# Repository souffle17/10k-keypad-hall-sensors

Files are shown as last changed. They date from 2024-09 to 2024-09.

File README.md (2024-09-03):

# 10k-keypad with variable input hall sensors

A 2x5 mechanical keypad circuit and PCB. The second row is made to support hall-effect switches with variable input, similar to those on rapid trigger/wooting keyboards, in addition to normal switches.          

Footprint "SW_MX_HS_CPG151101S11_1u_no_center" is modified from marbastlib's "SW_MX_HS_CPG151101S11_1u"

### Helpful resources:
- https://guide.zykrah.me/
- https://www.masterzen.fr/2020/05/03/designing-a-keyboard-part-1/
- https://wiki.ai03.com/books/pcb-design/chapter/pcb-designer-guide

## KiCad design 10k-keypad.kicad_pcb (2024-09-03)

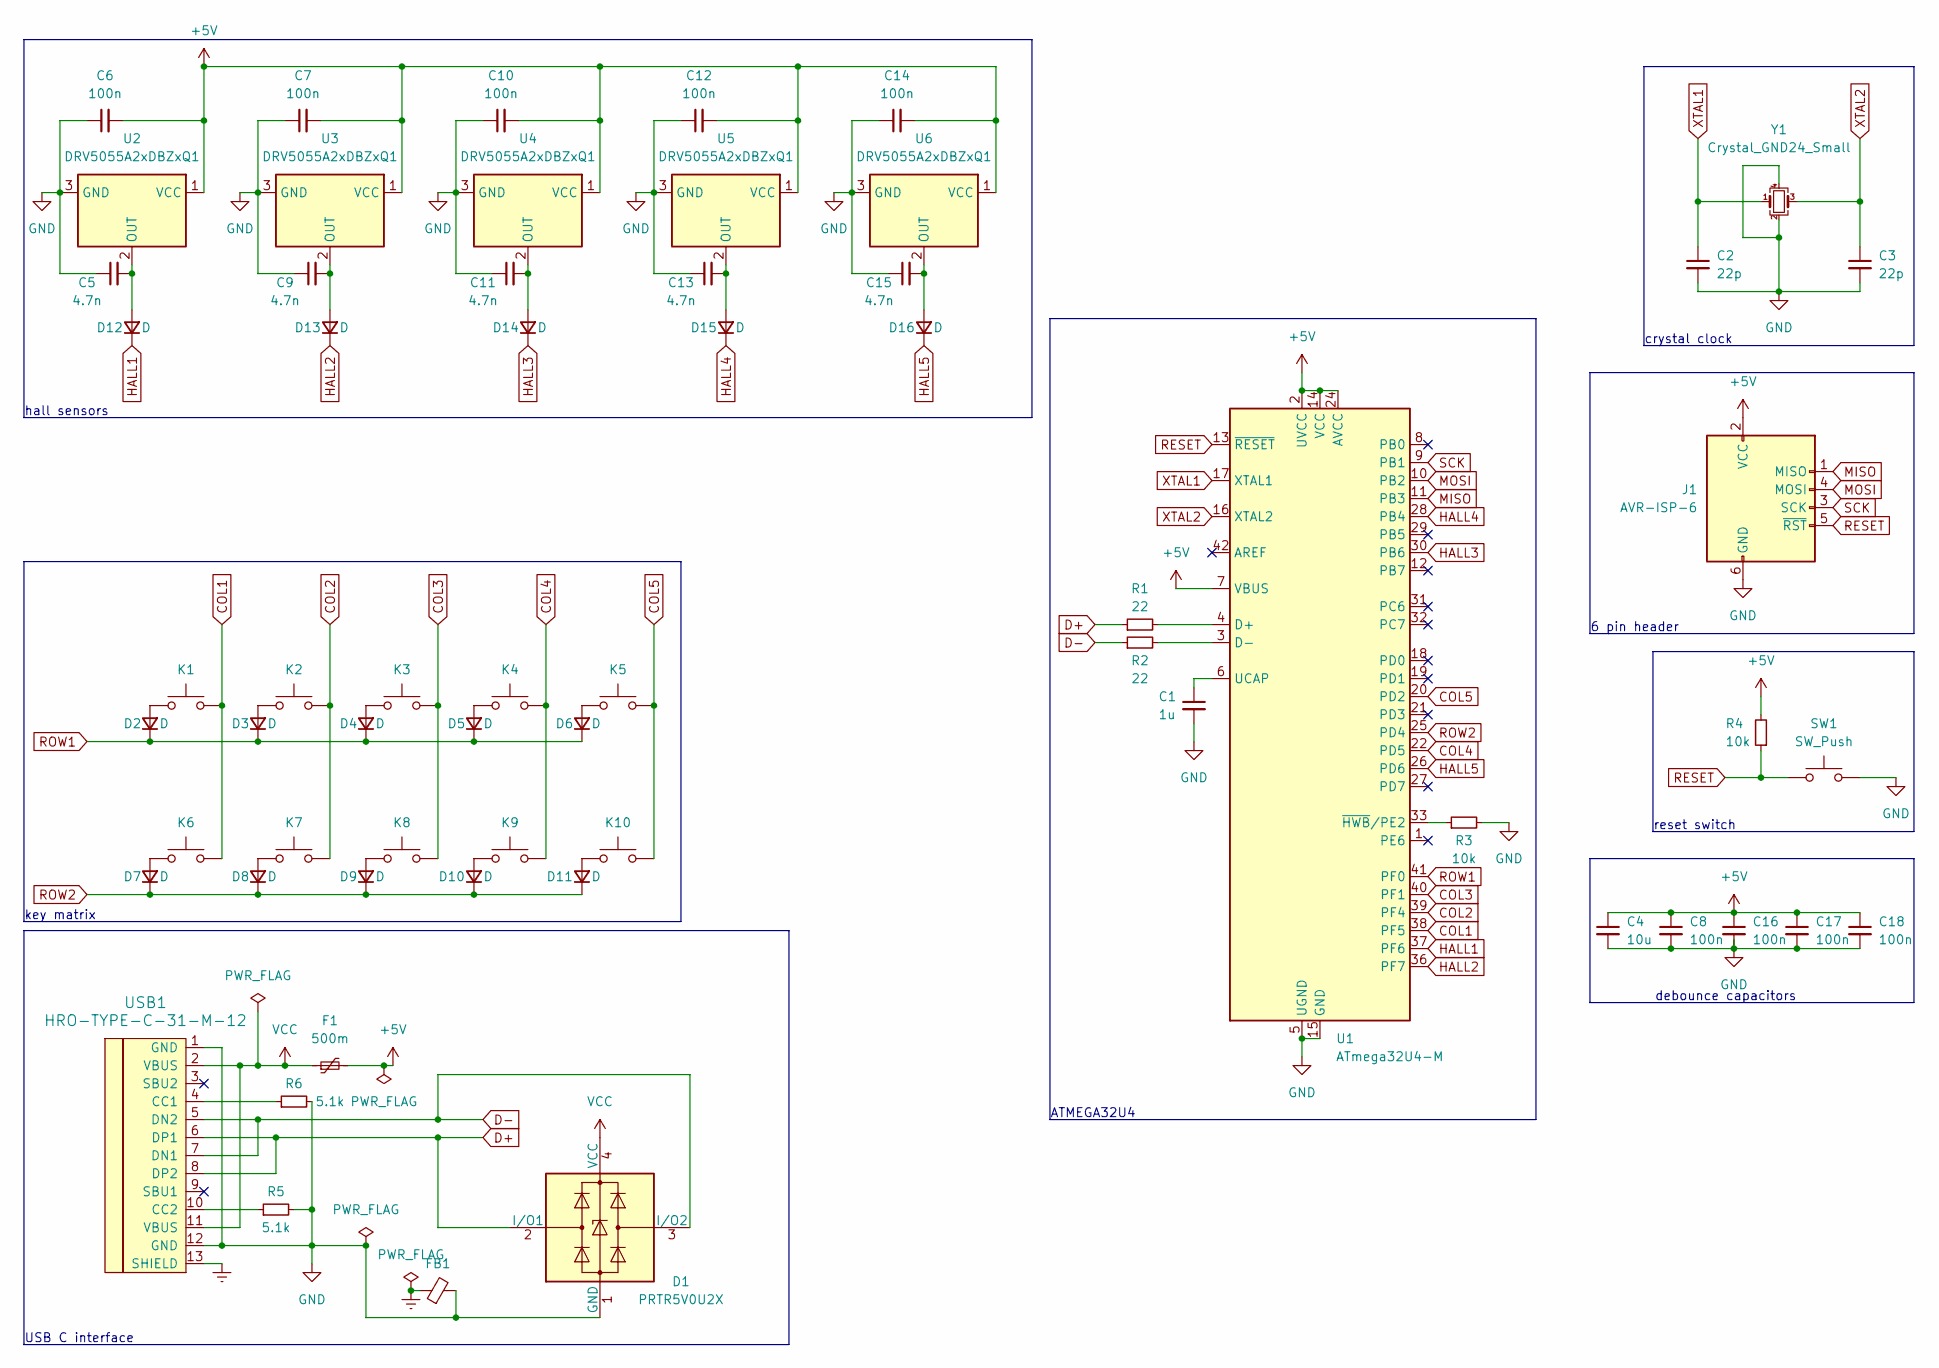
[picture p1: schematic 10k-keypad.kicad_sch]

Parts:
C1: 1u; C_0805_2012Metric_Pad1.18x1.45mm_HandSolder
C2, C3: 22p; C_0805_2012Metric_Pad1.18x1.45mm_HandSolder
C4: 10u; C_0805_2012Metric_Pad1.18x1.45mm_HandSolder
C5, C9, C11, C13, C15: 4.7n; C_0805_2012Metric_Pad1.18x1.45mm_HandSolder
C6, C7, C8, C10, C12, C14, C16, C17, C18: 100n; C_0805_2012Metric_Pad1.18x1.45mm_HandSolder
D1: PRTR5V0U2X; SOT-143
D2, D3, D4, D5, D6, D7, D8, D9, D10, D11, D12, D13, D14, D15, D16: D; D_SOD-123
F1: 500m; Fuse_1206_3216Metric_Pad1.42x1.75mm_HandSolder
FB1: FerriteBead_Small; L_0805_2012Metric_Pad1.15x1.40mm_HandSolder
J1: AVR-ISP-6; Reset_Pretty-Mask
K1, K2, K3, K4, K5: SW_Push; SW_MX_HS_CPG151101S11_1u
K6, K7, K8, K9, K10: SW_Push; SW_MX_HS_CPG151101S11_1u_no_center
R1, R2: 22; R_0805_2012Metric_Pad1.20x1.40mm_HandSolder
R3, R4: 10k; R_0805_2012Metric_Pad1.20x1.40mm_HandSolder
R5, R6: 5.1k; R_0805_2012Metric_Pad1.20x1.40mm_HandSolder
SW1: SW_Push; SW_SPST_SKQG_WithStem
U1: ATmega32U4-M; QFN-44-1EP_7x7mm_P0.5mm_EP5.2x5.2mm
U2, U3, U4, U5, U6: DRV5055A2xDBZxQ1; SOT-23
USB1: HRO-TYPE-C-31-M-12; HRO-TYPE-C-31-M-12-HandSoldering
Y1: Crystal_GND24_Small; Crystal_SMD_3225-4Pin_3.2x2.5mm_HandSoldering

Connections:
+5V: C4.1, C6.2, C7.2, C8.1, C10.2, C12.2, C14.2, C16.1, C17.1, C18.1, F1.2, J1.2 (VCC), R4.2, U1.2 (UVCC), U1.7 (VBUS), U1.14 (VCC), U1.24 (AVCC), U1.34 (VCC), U1.44 (AVCC), U2.1 (VCC), U3.1 (VCC), U4.1 (VCC), U5.1 (VCC), U6.1 (VCC)
COL1: K1.2, K6.2, U1.38 (PF5)
COL2: K2.2, K7.2, U1.39 (PF4)
COL3: K3.2, K8.2, U1.40 (PF1)
COL4: K4.2, K9.2, U1.22 (PD5)
COL5: K5.2, K10.2, U1.20 (PD2)
D+: D1.2 (I/O1), R1.1, USB1.6 (DP1), USB1.8 (DP2)
D-: D1.3 (I/O2), R2.1, USB1.5 (DN2), USB1.7 (DN1)
Earth: FB1.1, USB1.13 (SHIELD)
GND: C1.2, C2.2, C3.2, C4.2, C5.1, C6.1, C7.1, C8.2, C9.1, C10.1, C11.1, C12.1, C13.1, C14.1, C15.1, C16.2, C17.2, C18.2, D1.1 (GND), FB1.2, J1.6 (GND), R3.2, R5.2, R6.2, SW1.2, U1.5 (UGND), U1.15 (GND), U1.23 (GND), U1.35 (GND), U1.43 (GND), U1.45 (GND), U2.3 (GND), U3.3 (GND), U4.3 (GND), U5.3 (GND), U6.3 (GND), USB1.1 (GND), USB1.12 (GND), Y1.2, Y1.4
HALL1: D12.1 (K), U1.37 (PF6)
HALL2: D13.1 (K), U1.36 (PF7)
HALL3: D14.1 (K), U1.30 (PB6)
HALL4: D15.1 (K), U1.28 (PB4)
HALL5: D16.1 (K), U1.26 (PD6)
MISO: J1.1 (MISO), U1.11 (PB3)
MOSI: J1.4 (MOSI), U1.10 (PB2)
unnamed: D2.2 (A), K1.1
unnamed: D3.2 (A), K2.1
unnamed: D4.2 (A), K3.1
unnamed: D5.2 (A), K4.1
unnamed: D6.2 (A), K5.1
unnamed: D7.2 (A), K6.1
unnamed: D8.2 (A), K7.1
unnamed: D9.2 (A), K8.1
unnamed: D10.2 (A), K9.1
unnamed: D11.2 (A), K10.1
unnamed: C5.2, D12.2 (A), U2.2 (OUT)
unnamed: C9.2, D13.2 (A), U3.2 (OUT)
unnamed: C11.2, D14.2 (A), U4.2 (OUT)
unnamed: C13.2, D15.2 (A), U5.2 (OUT)
unnamed: C15.2, D16.2 (A), U6.2 (OUT)
unnamed: R1.2, U1.4 (D+)
unnamed: R2.2, U1.3 (D-)
unnamed: C1.1, U1.6 (UCAP)
unnamed: R3.1, U1.33 (~HWB/PE2)
unnamed: R6.1, USB1.4 (CC1)
unnamed: R5.1, USB1.10 (CC2)
RESET: J1.5 (~RST), R4.1, SW1.1, U1.13 (~RESET)
ROW1: D2.1 (K), D3.1 (K), D4.1 (K), D5.1 (K), D6.1 (K), U1.41 (PF0)
ROW2: D7.1 (K), D8.1 (K), D9.1 (K), D10.1 (K), D11.1 (K), U1.25 (PD4)
SCK: J1.3 (SCK), U1.9 (PB1)
VCC: D1.4 (VCC), F1.1, USB1.2 (VBUS), USB1.11 (VBUS)
XTAL1: C2.1, U1.17 (XTAL1), Y1.1
XTAL2: C3.1, U1.16 (XTAL2), Y1.3

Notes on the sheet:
crystal clock
hall sensors
key matrix
ATMEGA32U4
USB C interface
reset switch
6 pin header
debounce capacitors

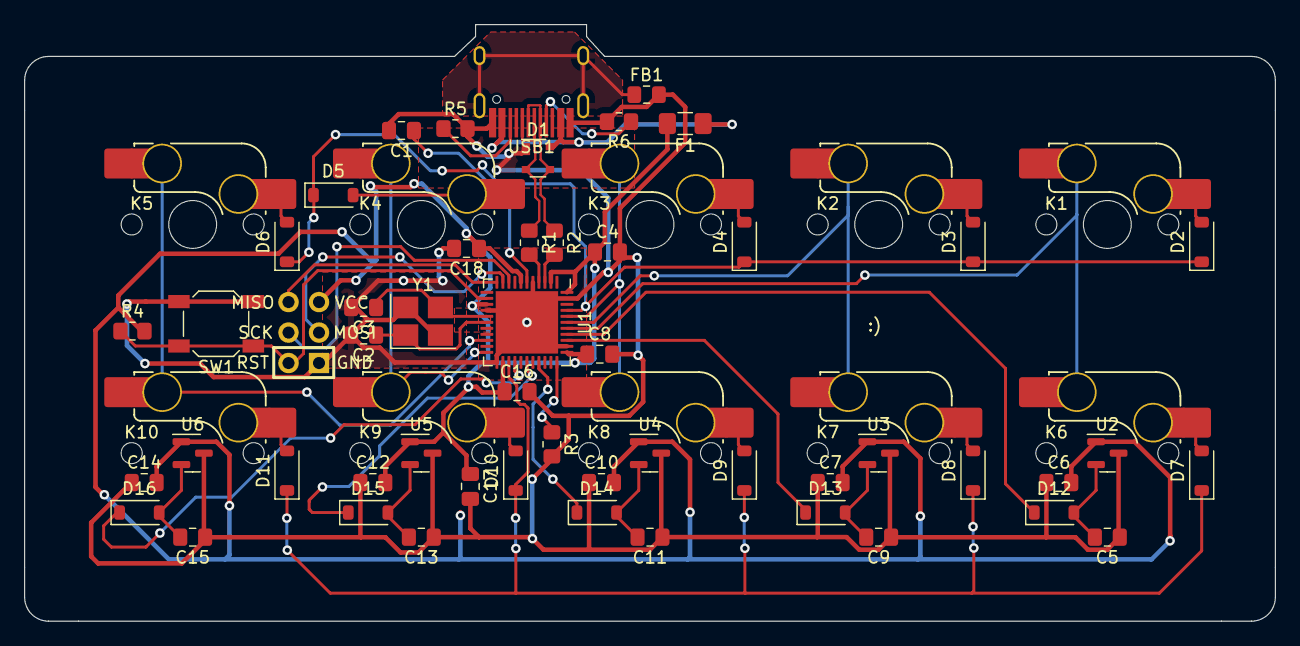
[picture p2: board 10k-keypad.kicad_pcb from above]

Board: 2 copper layers, 104.2 x 49.7 mm, 62 parts (0 on the bottom side), 45 nets.

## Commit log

2024-03-13 nearly whole schematic
    [10k-keypad.kicad_pcb, 10k-keypad.kicad_sch]
2024-03-13 finish schematic
    [10k-keypad.kicad_sch]
2024-03-13 start pcb
    [10k-keypad.kicad_pcb]
2024-03-13 crystal clock
    [10k-keypad.kicad_pcb, 10k-keypad.kicad_sch]
2024-03-13 finish routing
    [10k-keypad.kicad_pcb, 10k-keypad.kicad_sch]
2024-03-13 board cutout
    [10k-keypad.kicad_pcb]
2024-03-13 clearance fix
    [10k-keypad.kicad_pcb]
2024-03-13 fix edge cut
    [10k-keypad.kicad_pcb]
2024-03-14 add hall sensors to schematic
    [10k-keypad.kicad_sch]
2024-03-14 complete hall sensor schematic
    [10k-keypad.kicad_sch]
2024-03-14 hall sensor circuitry
    [10k-keypad.kicad_pcb, 10k-keypad.kicad_sch]
2024-03-14 narrower edges, fill fix
    [10k-keypad.kicad_pcb]
2024-03-14 finish pcb
    [10k-keypad.kicad_pcb]
2024-03-15 fix hall sensor circuitry
    [10k-keypad.kicad_pcb, 10k-keypad.kicad_sch]
2024-03-15 fix schematic, gerbers
    [10k-keypad.kicad_pcb, 10k-keypad.kicad_sch]
2024-03-15 fix pcb labels
    [10k-keypad.kicad_pcb]
2024-03-23 redo all routing, remove unused footprint
    [10k-keypad.kicad_pcb, 10k-keypad.kicad_sch]
2024-04-02 new board edge
    [10k-keypad.kicad_pcb]
2024-04-03 fix ground fill
    [10k-keypad.kicad_pcb]
2024-08-20 correct analog pins
    [10k-keypad.kicad_pcb, 10k-keypad.kicad_sch]
2024-09-03 move hall sensors to center
    [10k-keypad.kicad_pcb, 10k-keypad.kicad_sch]
